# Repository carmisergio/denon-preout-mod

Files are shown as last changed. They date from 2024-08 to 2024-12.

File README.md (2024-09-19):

# Denon AVR-X1300W Pre-out mod

The scope of this project is adding line-level outputs to the Denon AVR-X1300W AV Receiver.
This can be acheived by getting the low-level signals from the digital board of the receiver before they make their way to the power amp board.

The "Vampire PCB" is soldered directly to the digital board of the receiverr, and provides an 8-pin JST PH connector with the signals. A small length of shielded cable brings them to the back panel of the unit, where removing the AM/FM tuner unit provides a convenient place to mount a miniature circular connector.

An external "Gain Box" amplifies the ~150Vrms internal signal to a usable (variable) line level with a single stage of op-amp amplification. It also processes the 12V signal coming from the receiver to operate muting relays on the output and generate a standard 12V trigger signal which can be used to control the amplifiers.

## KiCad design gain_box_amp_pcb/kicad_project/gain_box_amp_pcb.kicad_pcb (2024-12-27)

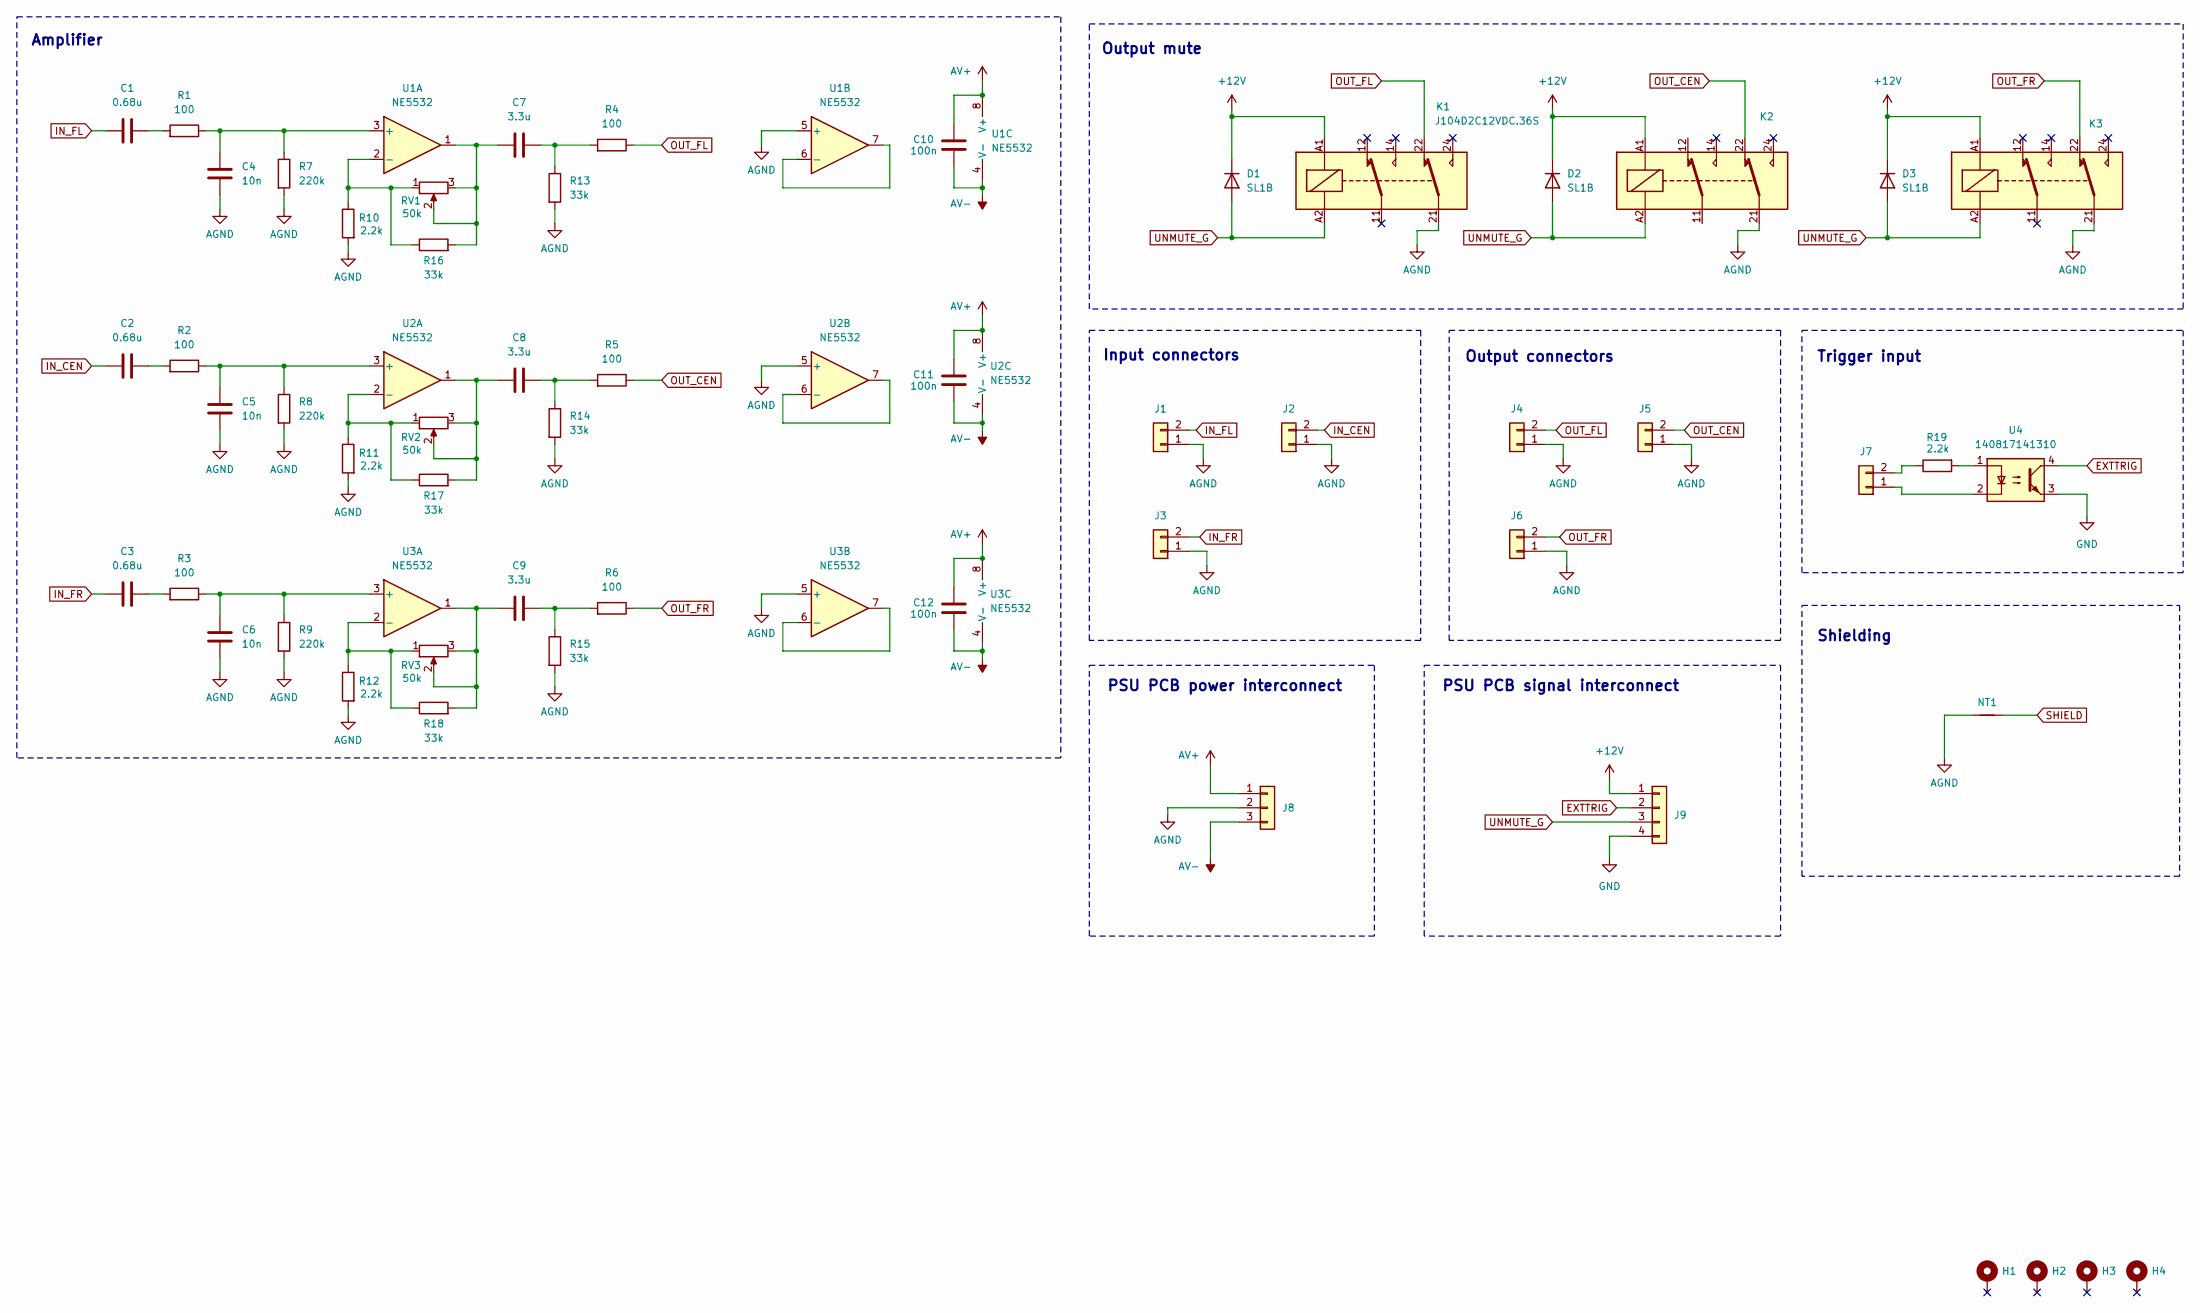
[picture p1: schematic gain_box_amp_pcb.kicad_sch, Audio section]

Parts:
C1, C2, C3: 0.68u; C_Rect_L7.2mm_W4.5mm_P5.00mm_FKS2_FKP2_MKS2_MKP2
C4, C5, C6: 10n; C_Rect_L7.2mm_W2.5mm_P5.00mm_FKS2_FKP2_MKS2_MKP2
C7, C8, C9: 3.3u; C_Rect_L13.0mm_W6.0mm_P10.00mm_FKS3_FKP3_MKS4
C10, C11, C12: 100n; C_Disc_D3.8mm_W2.6mm_P2.50mm
D1, D2, D3: SL1B; D_SOD-123
H1, H2, H3, H4: MountingHole_Pad; MountingHole_3.2mm_M3_Pad_Via
J1, J2, J3, J4, J5, J6, J7: Conn_01x02; JST_PH_B2B-PH-K_1x02_P2.00mm_Vertical
J8: Conn_01x03; JST_VH_B3P-VH-B_1x03_P3.96mm_Vertical
J9: Conn_01x04; JST_PH_B4B-PH-K_1x04_P2.00mm_Vertical
K1, K2, K3: J104D2C12VDC.36S; Relay_DPDT_Finder_30.22
NT1: NetTie_2; NetTie-2_THT_Pad1.0mm
R1, R2, R3, R4, R5, R6: 100; R_Axial_DIN0207_L6.3mm_D2.5mm_P7.62mm_Horizontal
R7, R8, R9: 220k; R_Axial_DIN0207_L6.3mm_D2.5mm_P7.62mm_Horizontal
R10, R11, R12, R19: 2.2k; R_Axial_DIN0207_L6.3mm_D2.5mm_P7.62mm_Horizontal
R13, R14, R15, R16, R17, R18: 33k; R_Axial_DIN0207_L6.3mm_D2.5mm_P7.62mm_Horizontal
RV1, RV2, RV3: 50k; TRIM_PV36W503C01B00
U1, U2, U3: NE5532; DIP-8_W7.62mm
U4: 140817141310; DIP-4_W7.62mm

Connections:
+12V: D1.1 (K), D2.1 (K), D3.1 (K), J9.1, K1.A1, K2.A1, K3.A1
AGND: C4.1, C5.1, C6.1, J1.1, J2.1, J3.1, J4.1, J5.1, J6.1, J8.2, K1.21, K2.21, K3.21, NT1.1, R7.2, R8.2, R9.2, R10.2, R11.2, R12.2, R13.2, R14.2, R15.2, U1.5 (+), U2.5 (+), U3.5 (+)
AV+: C10.2, C11.2, C12.2, J8.1, U1.8 (V+), U2.8 (V+), U3.8 (V+)
AV-: C10.1, C11.1, C12.1, J8.3, U1.4 (V-), U2.4 (V-), U3.4 (V-)
EXTTRIG: J9.2, U4.4
GND: J9.4, U4.3
IN_CEN: C2.1, J2.2
IN_FL: C1.1, J1.2
IN_FR: C3.1, J3.2
unnamed: C1.2, R1.2
unnamed: C2.2, R2.2
unnamed: C3.2, R3.2
unnamed: C7.1, R16.2, RV1.2, RV1.3, U1.1
unnamed: C7.2, R4.2, R13.1
unnamed: C8.1, R17.2, RV2.2, RV2.3, U2.1
unnamed: C8.2, R5.2, R14.1
unnamed: C9.1, R18.2, RV3.2, RV3.3, U3.1
unnamed: C9.2, R6.2, R15.1
unnamed: J7.1, U4.2
unnamed: J7.2, R19.1
unnamed: R19.2, U4.1
unnamed: C4.2, R1.1, R7.1, U1.3 (+)
unnamed: R10.1, R16.1, RV1.1, U1.2 (-)
unnamed: U1.6 (-), U1.7
unnamed: C5.2, R2.1, R8.1, U2.3 (+)
unnamed: R11.1, R17.1, RV2.1, U2.2 (-)
unnamed: U2.6 (-), U2.7
unnamed: C6.2, R3.1, R9.1, U3.3 (+)
unnamed: R12.1, R18.1, RV3.1, U3.2 (-)
unnamed: U3.6 (-), U3.7
OUT_CEN: J5.2, K2.22, R5.1
OUT_FL: J4.2, K1.22, R4.1
OUT_FR: J6.2, K3.22, R6.1
SHIELD: NT1.2
UNMUTE_G: D1.2 (A), D2.2 (A), D3.2 (A), J9.3, K1.A2, K2.A2, K3.A2

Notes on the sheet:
PSU PCB signal interconnect
Output connectors
Amplifier
Shielding
PSU PCB power interconnect
Trigger input
Output mute
Input connectors

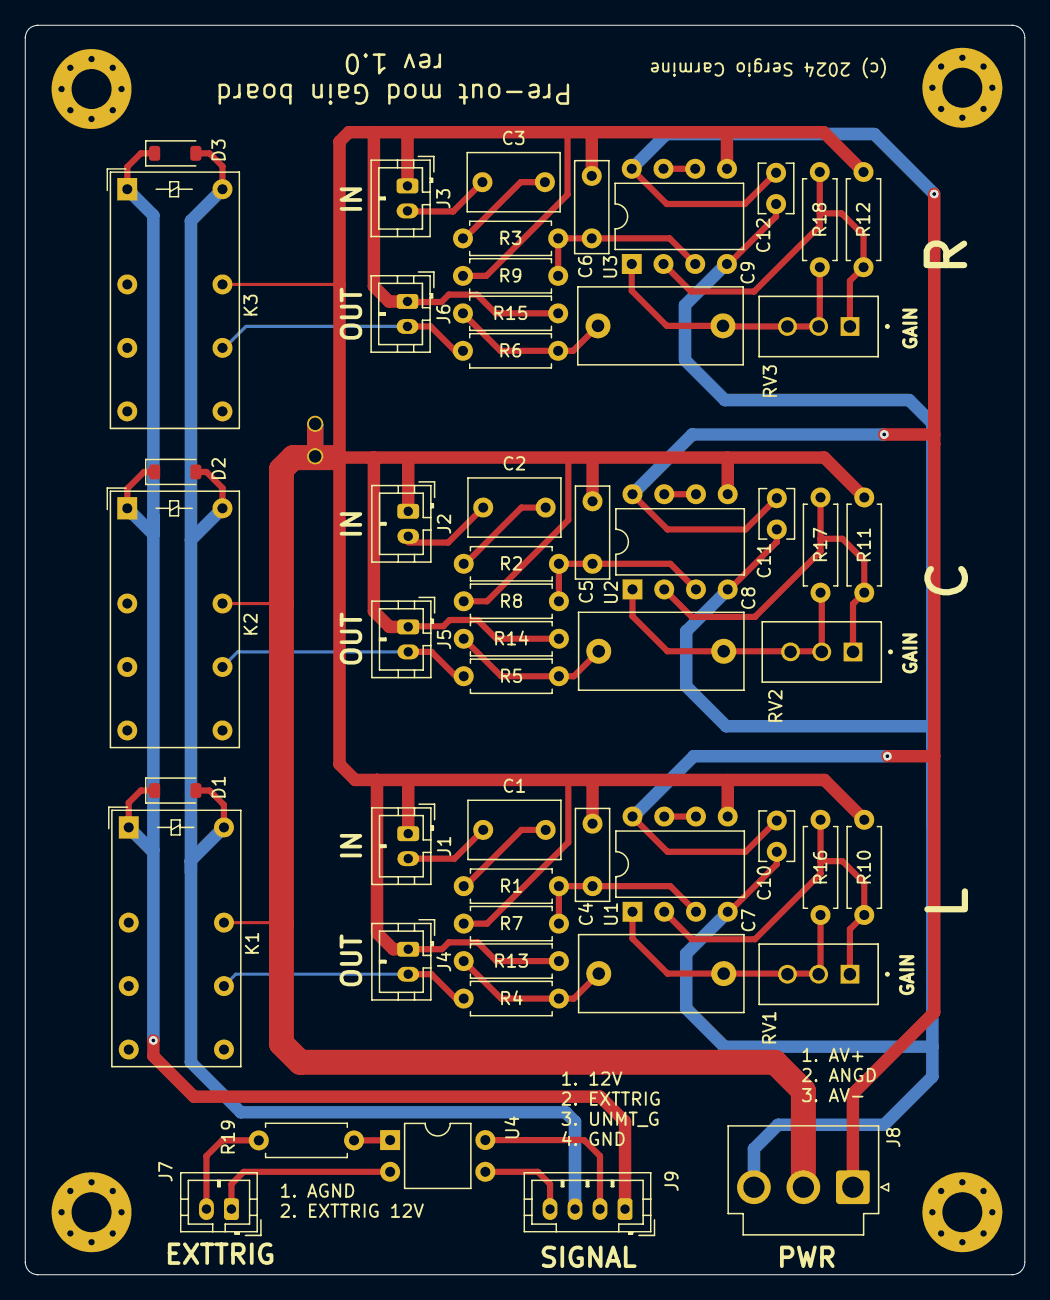
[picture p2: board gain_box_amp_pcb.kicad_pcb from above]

Board: 2 copper layers, 80.0 x 100.0 mm, 58 parts (0 on the bottom side), 34 nets.

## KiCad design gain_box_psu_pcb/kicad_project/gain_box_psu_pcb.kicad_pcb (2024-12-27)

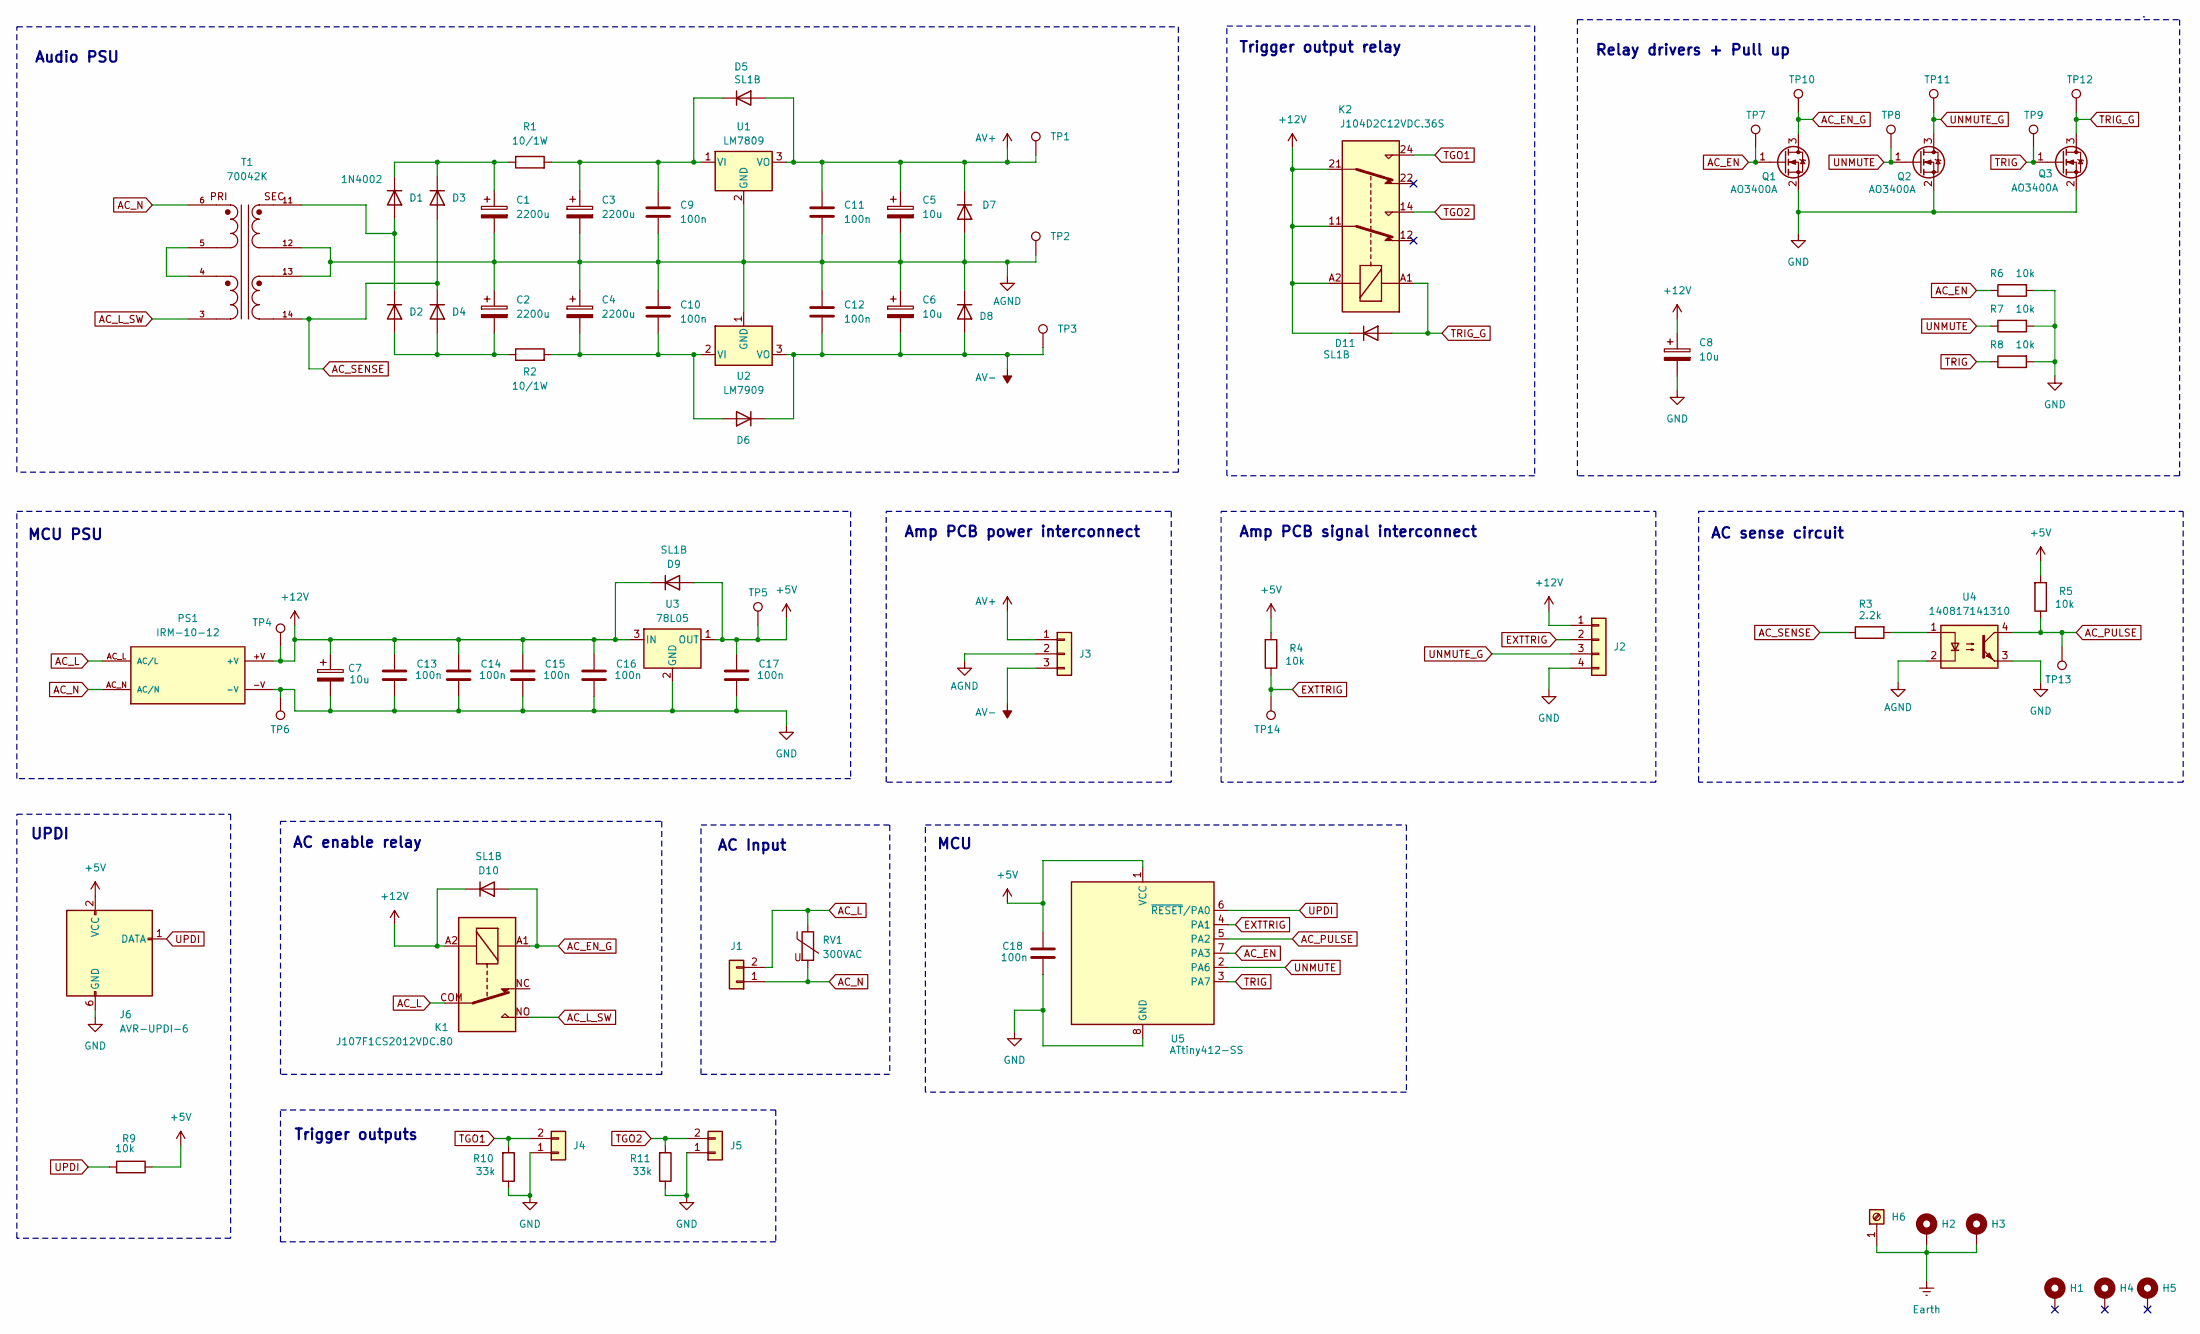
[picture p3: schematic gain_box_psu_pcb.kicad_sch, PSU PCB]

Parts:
C1, C2, C3, C4: 2200u; CP_Radial_D16.0mm_P7.50mm
C5, C6, C7, C8: 10u; CP_Radial_D5.0mm_P2.00mm
C9, C10, C11, C12, C13, C14, C15, C16, C17, C18: 100n; C_Disc_D3.8mm_W2.6mm_P2.50mm
D1, D2, D3, D4: 1N4002; D_DO-41_SOD81_P10.16mm_Horizontal
D5, D6, D7, D8, D9, D10, D11: SL1B; D_SOD-123
H1, H2, H3, H4, H5: MountingHole_Pad; MountingHole_3.2mm_M3_Pad_Via
H6: Screw_Terminal_01x01; KEYSTONE_7760
J1: Conn_01x02; JST_VH_B2P3-VH_1x02_P7.92mm_Vertical
J2: Conn_01x04; JST_PH_B4B-PH-K_1x04_P2.00mm_Vertical
J3: Conn_01x03; JST_VH_B3P-VH-B_1x03_P3.96mm_Vertical
J4, J5: Conn_01x02; JST_PH_B2B-PH-K_1x02_P2.00mm_Vertical
J6: AVR-UPDI-6; PinHeader_2x03_P2.54mm_Vertical
K1: J107F1CS2012VDC.80; RELAY_SRD-C
K2: J104D2C12VDC.36S; Relay_DPDT_Finder_30.22
PS1: IRM-10-12; CONV_IRM-10-12; PARTREV 2022-04-25
Q1, Q2, Q3: AO3400A; SOT-23
R1, R2: 10/1W; R_Axial_DIN0411_L9.9mm_D3.6mm_P12.70mm_Horizontal
R3: 2.2k; R_Axial_DIN0207_L6.3mm_D2.5mm_P7.62mm_Horizontal
R4, R5, R6, R7, R8, R9: 10k; R_0805_2012Metric_Pad1.20x1.40mm_HandSolder
R10, R11: 33k; R_Axial_DIN0207_L6.3mm_D2.5mm_P7.62mm_Horizontal
RV1: 300VAC; RV_Disc_D9mm_W4.5mm_P5mm
T1: 70042K; XFMR_70042K; PARTREV 11/20
TP1, TP2, TP3, TP4, TP5, TP6: TestPoint; TestPoint_Pad_D2.0mm
TP7, TP8, TP9, TP10, TP11, TP12, TP13, TP14: TestPoint; TestPoint_Pad_D1.0mm
U1: LM7809; TO-220-3_Vertical
U2: LM7909; TO-220-3_Vertical
U3: 78L05; SOT-89-3
U4: 140817141310; DIP-4_W7.62mm
U5: ATtiny412-SS; SOIC-8_3.9x4.9mm_P1.27mm

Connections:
+5V: C17.1, C18.1, D9.2 (A), J6.2 (VCC), R4.2, R5.2, R9.1, TP5.1, U3.1 (OUT), U5.1 (VCC)
+12V: C7.1, C8.1, C13.1, C14.1, C15.1, C16.1, D9.1 (K), D10.1 (K), D11.1 (K), J2.1, K1.A2, K2.11, K2.21, K2.A2, PS1.+V, TP4.1, U3.3 (IN)
AC_EN: Q1.1 (G), R6.1, TP7.1, U5.7 (PA3)
AC_EN_G: D10.2 (A), K1.A1, Q1.3 (D), TP10.1
AC_L: J1.2, K1.COM, PS1.AC_L (AC/L), RV1.1
AC_L_SW: K1.NO, T1.3
AC_N: J1.1, PS1.AC_N (AC/N), RV1.2, T1.6
AC_PULSE: R5.1, TP13.1, U4.4, U5.5 (PA2)
AC_SENSE: D3.2 (A), D4.1 (K), R3.1, T1.14
AGND: C1.2, C2.1, C3.2, C4.1, C5.2, C6.1, C9.2, C10.1, C11.2, C12.1, D7.2 (A), D8.1 (K), J3.2, T1.12, T1.13, TP2.1, U1.2 (GND), U2.1 (GND), U4.2
AV+: C5.1, C11.1, D5.2 (A), D7.1 (K), J3.1, TP1.1, U1.3 (VO)
AV-: C6.2, C12.2, D6.1 (K), D8.2 (A), J3.3, TP3.1, U2.3 (VO)
EXTTRIG: J2.2, R4.1, TP14.1, U5.4 (PA1)
Earth: H2.1, H3.1, H6.1
GND: C7.2, C8.2, C13.2, C14.2, C15.2, C16.2, C17.2, C18.2, J2.4, J4.1, J5.1, J6.6 (GND), PS1.-V, Q1.2 (S), Q2.2 (S), Q3.2 (S), R6.2, R7.2, R8.2, R10.1, R11.1, TP6.1, U3.2 (GND), U4.3, U5.8 (GND)
unnamed: D1.2 (A), D2.1 (K), T1.11
unnamed: C1.1, D1.1 (K), D3.1 (K), R1.1
unnamed: C2.2, D2.2 (A), D4.2 (A), R2.1
unnamed: C3.1, C9.1, D5.1 (K), R1.2, U1.1 (VI)
unnamed: C4.2, C10.2, D6.2 (A), R2.2, U2.2 (VI)
unnamed: R3.2, U4.1
unnamed: T1.4, T1.5
TGO1: J4.2, K2.24, R10.2
TGO2: J5.2, K2.14, R11.2
TRIG: Q3.1 (G), R8.1, TP9.1, U5.3 (PA7)
TRIG_G: D11.2 (A), K2.A1, Q3.3 (D), TP12.1
UNMUTE: Q2.1 (G), R7.1, TP8.1, U5.2 (PA6)
UNMUTE_G: J2.3, Q2.3 (D), TP11.1
UPDI: J6.1 (DATA), R9.2, U5.6 (~RESET/PA0)

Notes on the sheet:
Amp PCB signal interconnect
Trigger output relay
Amp PCB power interconnect
AC sense circuit
Relay drivers + Pull up
Audio PSU
Trigger outputs
MCU PSU
AC Input
AC enable relay
UPDI
MCU

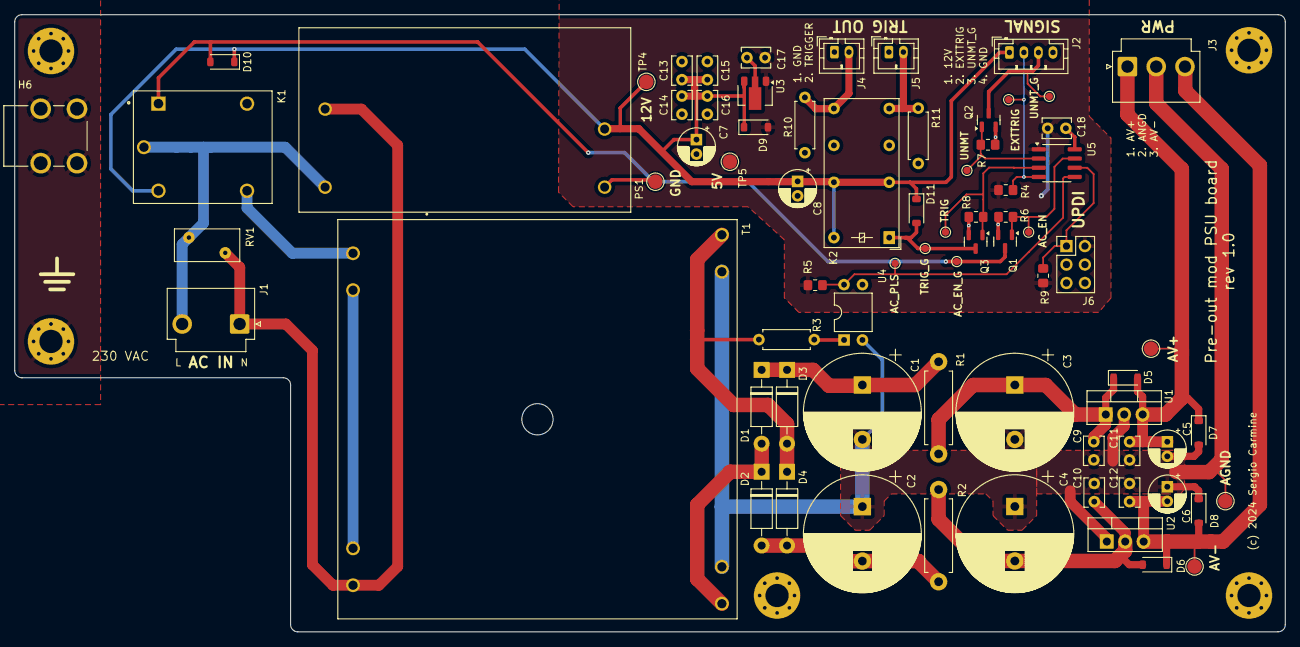
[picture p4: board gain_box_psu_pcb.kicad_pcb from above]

Board: 2 copper layers, 175.0 x 85.0 mm, 79 parts (0 on the bottom side), 29 nets.

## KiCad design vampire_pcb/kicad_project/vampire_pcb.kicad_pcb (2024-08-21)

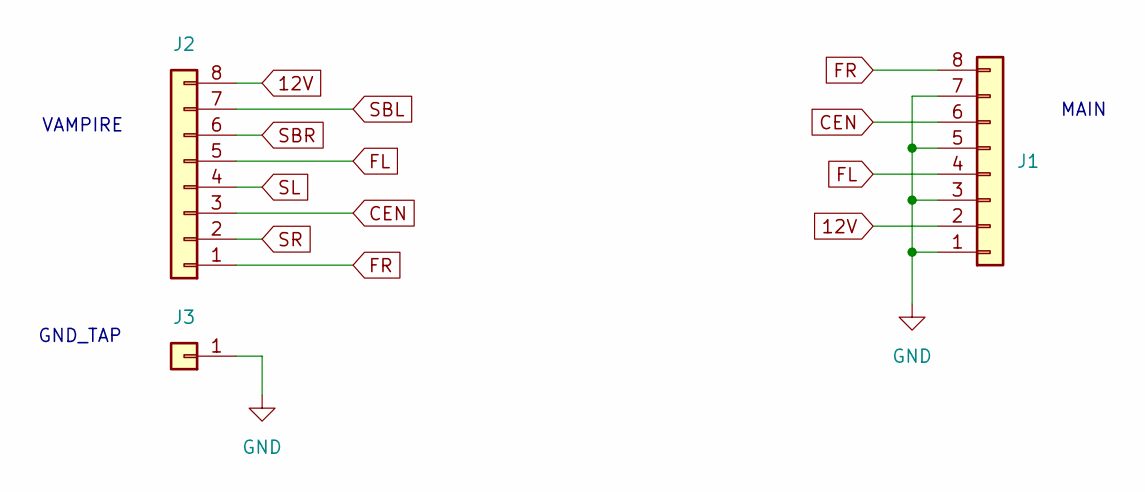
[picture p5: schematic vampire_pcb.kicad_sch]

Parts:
J1: Conn_01x08; JST_PH_B8B-PH-K_1x08_P2.00mm_Vertical
J2: VAMPIRE_EDGE; PinSocket_1x08_P2.54mm_Vertical
J3: GND_PAD; TestPoint_Pad_4.0x4.0mm

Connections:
12V: J1.2, J2.8
CEN: J1.6, J2.3
FL: J1.4, J2.5
FR: J1.8, J2.1
GND: J1.1, J1.3, J1.5, J1.7, J3.1
SBL: J2.7
SBR: J2.6
SL: J2.4
SR: J2.2

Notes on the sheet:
GND_TAP
MAIN
VAMPIRE

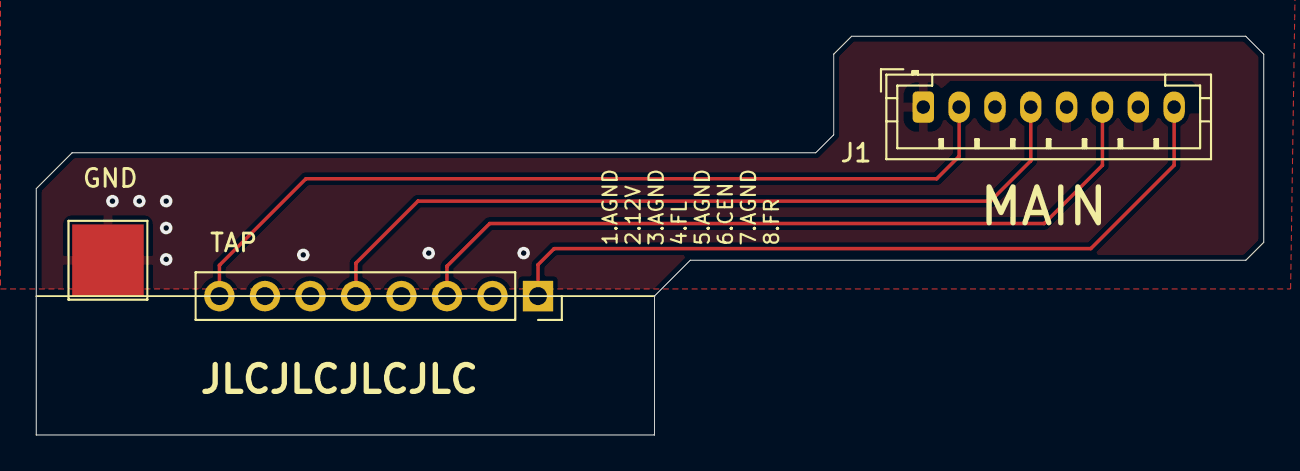
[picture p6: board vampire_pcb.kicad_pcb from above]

Board: 2 copper layers, 68.5 x 22.2 mm, 3 parts (0 on the bottom side), 5 nets.

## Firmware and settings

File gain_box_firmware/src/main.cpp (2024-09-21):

#include <avr/io.h>
#include <util/delay.h>

#include "init.hpp"
#include "millis.hpp"
#include "gpio.hpp"
#include "signal.hpp"

// Pin configuration
#if defined(__AVR_ATmega328P__)
constexpr Pin IN_AC_PULSE_PIN = Pin::P_PD3;
constexpr Pin IN_EXTTRIG_PIN = Pin::P_PD4;
constexpr Pin OUT_AC_EN_PIN = Pin::P_PB3;
constexpr Pin OUT_TRIG_PIN = Pin::P_PB4;
constexpr Pin OUT_UNMUTE_PIN = Pin::P_PB5;
#elif defined(__AVR_ATtiny412__)
constexpr Pin IN_AC_PULSE_PIN = Pin::P_PA1;
constexpr Pin IN_EXTTRIG_PIN = Pin::P_PA2;
constexpr Pin OUT_AC_EN_PIN = Pin::P_PA3;
constexpr Pin OUT_UNMUTE_PIN = Pin::P_PA6;
constexpr Pin OUT_TRIG_PIN = Pin::P_PA7;
#else
#error Unsupported MCU!
#endif

// Delay configuration
constexpr uint32_t D_AC_DETECT_TIME = 1000;
constexpr uint32_t D_AC_EN_OFF_TIME = 1000;
constexpr uint32_t D_EXTTRIG_TIME = 10000;
constexpr uint32_t D_AC_OK_TIME = 2000;
constexpr uint32_t D_TRIG_OUT_TIME = 200;

int main()
{
  // Initizlize MCU
  mcu_init();

  // Start millis() counter
  millis_init();

  // IO
  DigitalInput in_ac_pulse(IN_AC_PULSE_PIN, InputCfg::INVERTED_PULLUP);
  DigitalInput in_exttrig(IN_EXTTRIG_PIN, InputCfg::INVERTED_PULLUP);
  DigitalOutput out_ac_en(OUT_AC_EN_PIN);
  DigitalOutput out_unmute(OUT_UNMUTE_PIN);
  DigitalOutput out_trig(OUT_TRIG_PIN);

  // // Delays
  SignalDelay d_ac_detect(D_AC_DETECT_TIME, DelayType::FALLING);
  SignalDelay d_ac_en_off(D_AC_EN_OFF_TIME, DelayType::FALLING);
  SignalDelay d_exttrig_ok(D_EXTTRIG_TIME, DelayType::RISING);
  SignalDelay d_ac_ok(D_AC_OK_TIME, DelayType::RISING);
  SignalDelay d_trig_out(D_TRIG_OUT_TIME, DelayType::RISING);

  // Main loop
  while (true)
  {
    // Get current time
    uint32_t time = millis();

    // Get values of inputs
    bool ac_pulse = in_ac_pulse.get(); // Inverted
    bool exttrig = in_exttrig.get();   // Inverted

    // Process
    bool ac_detect = d_ac_detect.process(ac_pulse, time); // True when AC is present
    bool ac_en = d_ac_en_off.process(exttrig, time);      // AC_EN output signal
    bool exttrig_ok = d_exttrig_ok.process(exttrig, time);
    bool ac_ok = d_ac_ok.process(ac_detect, time);
    bool sigchain_ok = exttrig_ok && ac_ok;            // UNMUTE output signal
    bool trig = d_trig_out.process(sigchain_ok, time); // TRIG output signal

    // Write outputs
    out_ac_en.change(ac_en);
    out_unmute.change(sigchain_ok);
    out_trig.change(trig);
  }
}

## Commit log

2024-04-10 vampire_pcb: first commit
    [vampire_pcb-B_Courtyard.gbr, vampire_pcb-B_Cu.gbl, vampire_pcb-B_Fab.gbr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]
2024-04-10 vampire_pcb: use copper pour for GND on front
    [vampire_pcb.kicad_pcb]
2024-08-21 Update PCB
    [vampire_pcb-B_Courtyard.gbr, vampire_pcb-B_Cu.gbl, vampire_pcb-B_Fab.gbr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]
2024-09-19 Vampire PCB
2024-09-19 Gain box PCB + firmware
    [gain_box.kicad_pcb, gain_box.kicad_sch]
2024-09-21 firmware: implement millis for ATtiny412
2024-09-21 gain_box: preliminary amp section layout
    [gain_box.kicad_pcb, gain_box.kicad_sch]
2024-09-22 gain_box: first audio PSU layout
    [gain_box.kicad_pcb, gain_box.kicad_sch]
2024-09-28 Split PSU PCB
    [gain_box-B_Courtyard.gbr, gain_box-B_Cu.gbl, gain_box-B_Fab.gbr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]
2024-09-28 Layout AMP PCB
    [gain_box-B_Courtyard.gbr, gain_box-B_Cu.gbl, gain_box-B_Fab.gbr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]
2024-12-26 Shorten PSU PCB
    [gain_box_amp_pcb.kicad_pcb, gain_box_psu_pcb.kicad_pcb, gain_box_psu_pcb.kicad_sch]
2024-12-27 Update PSU PCB
    [gain_box_psu_pcb.kicad_pcb, gain_box_psu_pcb.kicad_sch]
2024-12-27 Fix routing error
    [gain_box_amp_pcb.kicad_pcb, gain_box_amp_pcb.kicad_sch]

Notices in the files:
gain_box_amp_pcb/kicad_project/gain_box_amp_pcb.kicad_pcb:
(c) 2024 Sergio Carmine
